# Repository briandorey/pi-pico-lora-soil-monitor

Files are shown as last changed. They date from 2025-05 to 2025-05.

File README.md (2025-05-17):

# Allotment LoRa Wireless Moisture Monitor

This repository contains the hardware and software files for the allotment LoRa wireless moisture monitoring system that can be found on https://www.briandorey.com/post/pi-pico-lora-remote-soil-monitor

The system consists of a sender and receiver, both using a Raspberry Pi Pico and a LoRa wireless module. The sensor reads moisuture, temperature and humitidy values from a series of sensors and sends the data wirelessly to the receiver module using the LoRa wireless protocol.

## Components
###  1. AllotmentSender
   - Hardware: Includes the design and implementation of the sender's physical components.
   - Firmware: Software running on the sender hardware to read sensor data, update an e-paper display and send the data to the home receiver via a LoRa module.

### 2. Home Receiver
   - Hardware: Details about the receiver's physical components.
   - Firmware: Software running on the receiver hardware to handle incoming LoRa data and relay it to an MQTT broker

## License

MIT License

Copyright (c) 2025 Brian Dorey

Permission is hereby granted, free of charge, to any person obtaining a copy of this software and associated documentation files (the "Software"), to deal in the Software without restriction, including without limitation the rights to use, copy, modify, merge, publish, distribute, sublicense, and/or sell copies of the Software, and to permit persons to whom the Software is furnished to do so, subject to the following conditions:

The above copyright notice and this permission notice shall be included in all copies or substantial portions of the Software.

THE SOFTWARE IS PROVIDED "AS IS", WITHOUT WARRANTY OF ANY KIND, EXPRESS OR IMPLIED, INCLUDING BUT NOT LIMITED TO THE WARRANTIES OF MERCHANTABILITY, FITNESS FOR A PARTICULAR PURPOSE AND NONINFRINGEMENT. IN NO EVENT SHALL THE AUTHORS OR COPYRIGHT HOLDERS BE LIABLE FOR ANY CLAIM, DAMAGES OR OTHER LIABILITY, WHETHER IN AN ACTION OF CONTRACT, TORT OR OTHERWISE, ARISING FROM, OUT OF OR IN CONNECTION WITH THE SOFTWARE OR THE USE OR OTHER DEALINGS IN THE SOFTWARE.

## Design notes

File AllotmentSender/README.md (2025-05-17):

# Allotment Sender

This directory contains the hardware and software components and documentation for the Sender module. Full details for the allotment LoRa wireless moisture monitoring system that can be found on https://www.briandorey.com/post/pi-pico-lora-remote-soil-monitor

Below is a summary of the contents:

- **Hardware**: PCB files for the sender hardware.
- **sender-firmware**: Raspberry Pi Pico firmware for the sender in MicroPython.

The allotment sender consists of the following components.

[Raspberry Pi Pico](https://www.raspberrypi.com/documentation/microcontrollers/pico-series.html#pico-1-family) microcontroller  
[Waveshare Pico-LoRa-SX1262-868M](https://www.waveshare.com/wiki/Pico-LoRa-SX1262-868M) LoRa module  
[AB Electronics UK ADC Pi](https://www.abelectronics.co.uk/p/69/adc-pi) analogue to digital converter  
[Microchip MCP9803](https://www.microchip.com/en-us/product/MCP9803) temperature sensor  
AHT20 temperature and humidity sensor  
[WeAct 2.9 Inch E-paper Module](https://www.aliexpress.com/item/1005004644515880.html)

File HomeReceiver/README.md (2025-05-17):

# Home-Receiver

This directory contains the files for the home receiver part of the allotment LoRa wireless moisture monitoring system that can be found on https://www.briandorey.com/post/pi-pico-lora-remote-soil-monitor

The receiver consists of a [Raspberry Pi Pico W](https://www.raspberrypi.com/documentation/microcontrollers/pico-series.html#pico-1-family) connected to a [Waveshare Pico-LoRa-SX1262-868M](https://www.waveshare.com/wiki/Pico-LoRa-SX1262-868M) module.

## Configuration

config.py contains all of the receiver program configuration options.

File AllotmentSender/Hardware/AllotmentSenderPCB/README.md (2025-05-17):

# Allotment Sender

This directory contains the PCB files for the sender hardware. Full details for the allotment LoRa wireless moisture monitoring system that can be found on https://www.briandorey.com/post/pi-pico-lora-remote-soil-monitor

Subdirectories

- **bom**: HTML bom showing the locations of the components on the PCB.
- **production**: Gerber files and production files needed to manufacture the board.

The PCB was designed with Kicad version 9.0.1.

## KiCad

KiCad is an open-source software suite for creating electronic circuit designs and PCB layouts. It provides tools for schematic capture, PCB layout, and 3D visualization of the design.

You can download KiCad from the official website: https://kicad.org/download/

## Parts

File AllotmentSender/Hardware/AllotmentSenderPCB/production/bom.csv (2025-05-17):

Designator | Footprint | Quantity | Value | LCSC Part #
A1 | RaspberryPi_Pico_Common_THT | 1 | RaspberryPi_Pico
C1 | 0805 | 1 | 1µF
C2, C4 | 0805 | 2 | 10µF
C3, C6 | 0805 | 2 | 10nF
C5 | 0805 | 1 | 100nF
J1 | Raspberry_Pi_Zero_Socketed_THT | 1 | Raspberry Pi Header
J2 | PinHeader_1x08_P2.54mm_Vertical | 1 | Screw_Terminal_3V3
J3 | PinHeader_1x08_P2.54mm_Vertical | 1 | Screw_Terminal_GND
J4 | Samtec_HPM-02-01-x-S_Straight_1x02_Pitch5.08mm | 1 | POWER_IN
J5 | PinHeader_1x05_P2.54mm_Vertical | 1 | I2C Bus
J6 | PinHeader_1x03_P2.54mm_Vertical | 1 | UART
R1 | 0805 | 1 | 2K3
R2 | 0805 | 1 | 1K
R3, R4, R5 | 0805 | 3 | 10K
U1 | Pico-LoRa-SX1262-868M | 1 | Pico-LoRa-SX1262-868M
U2 | SOIC-8-1EP_3.9x4.9mm_P1.27mm_EP2.41x3.81mm | 1 | LP3878-ADJ
U3 | PinHeader_1x08_P2.54mm_Vertical | 1 | 2.9" Epaper Module
U4 | SOIC-8_3.9x4.9mm_P1.27mm | 1 | MCP9803

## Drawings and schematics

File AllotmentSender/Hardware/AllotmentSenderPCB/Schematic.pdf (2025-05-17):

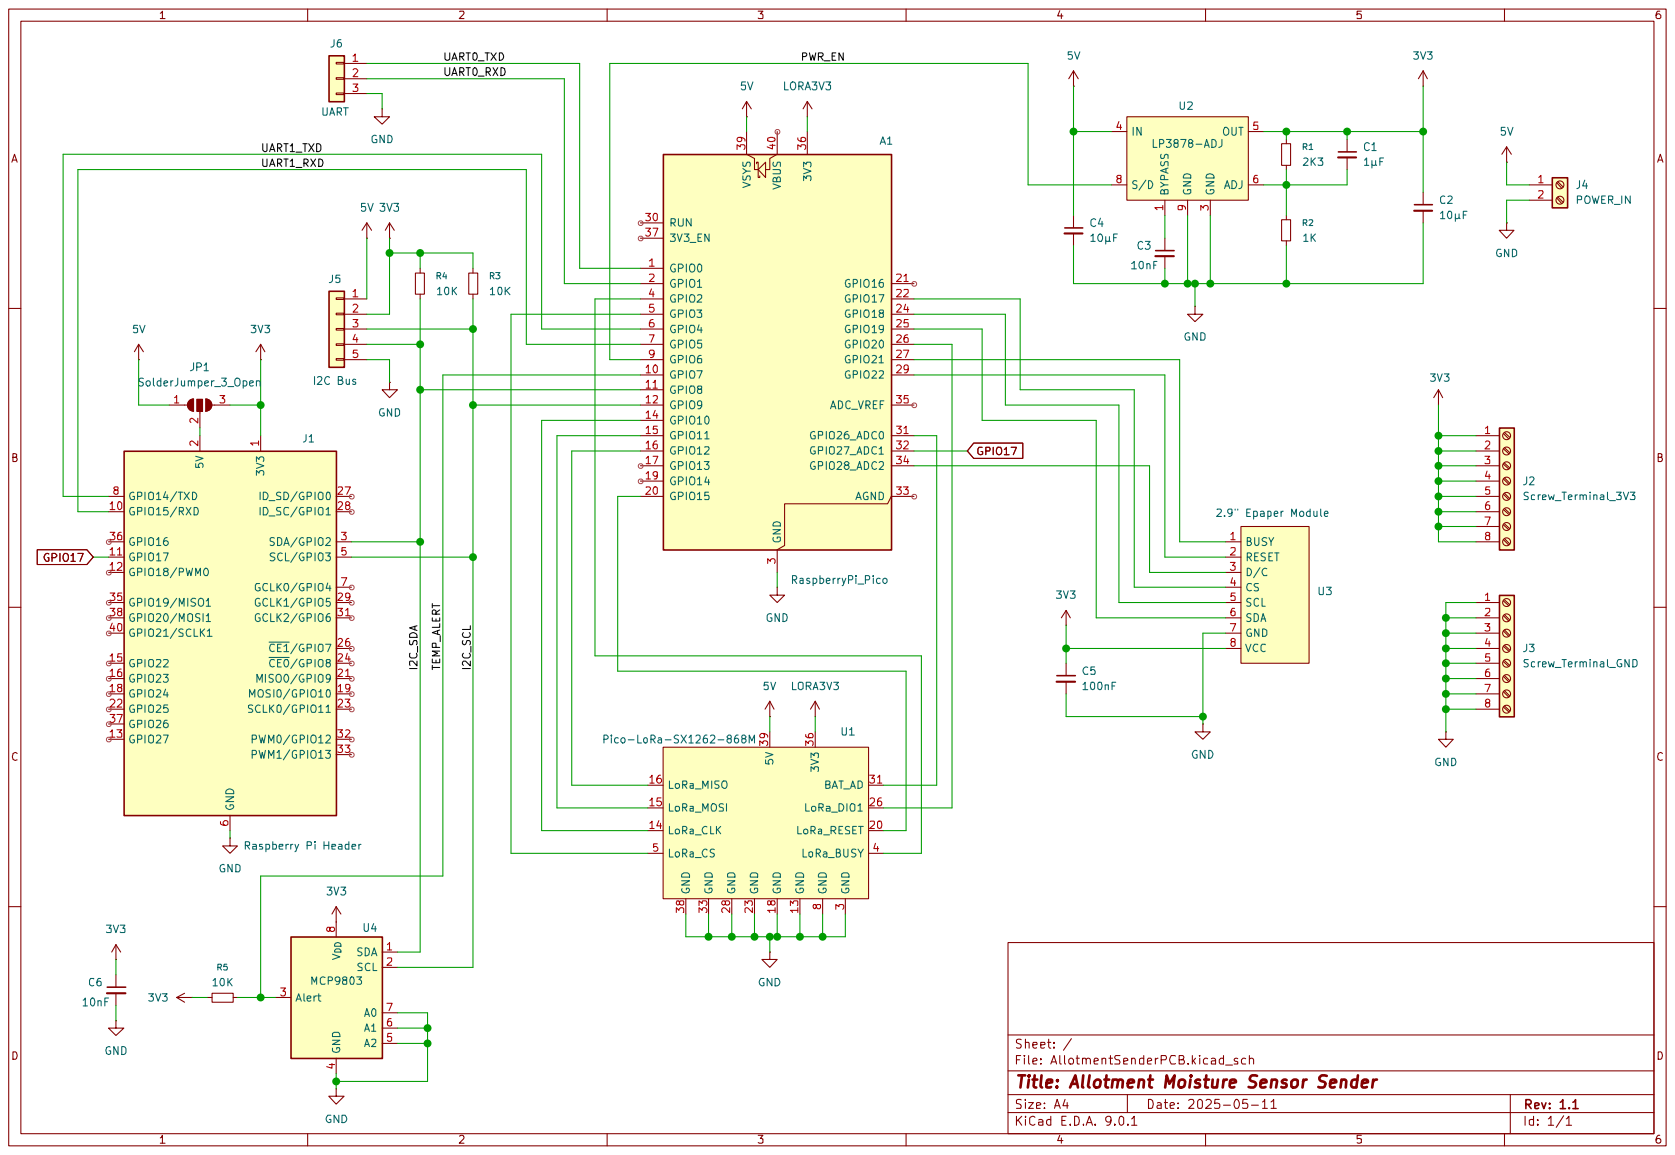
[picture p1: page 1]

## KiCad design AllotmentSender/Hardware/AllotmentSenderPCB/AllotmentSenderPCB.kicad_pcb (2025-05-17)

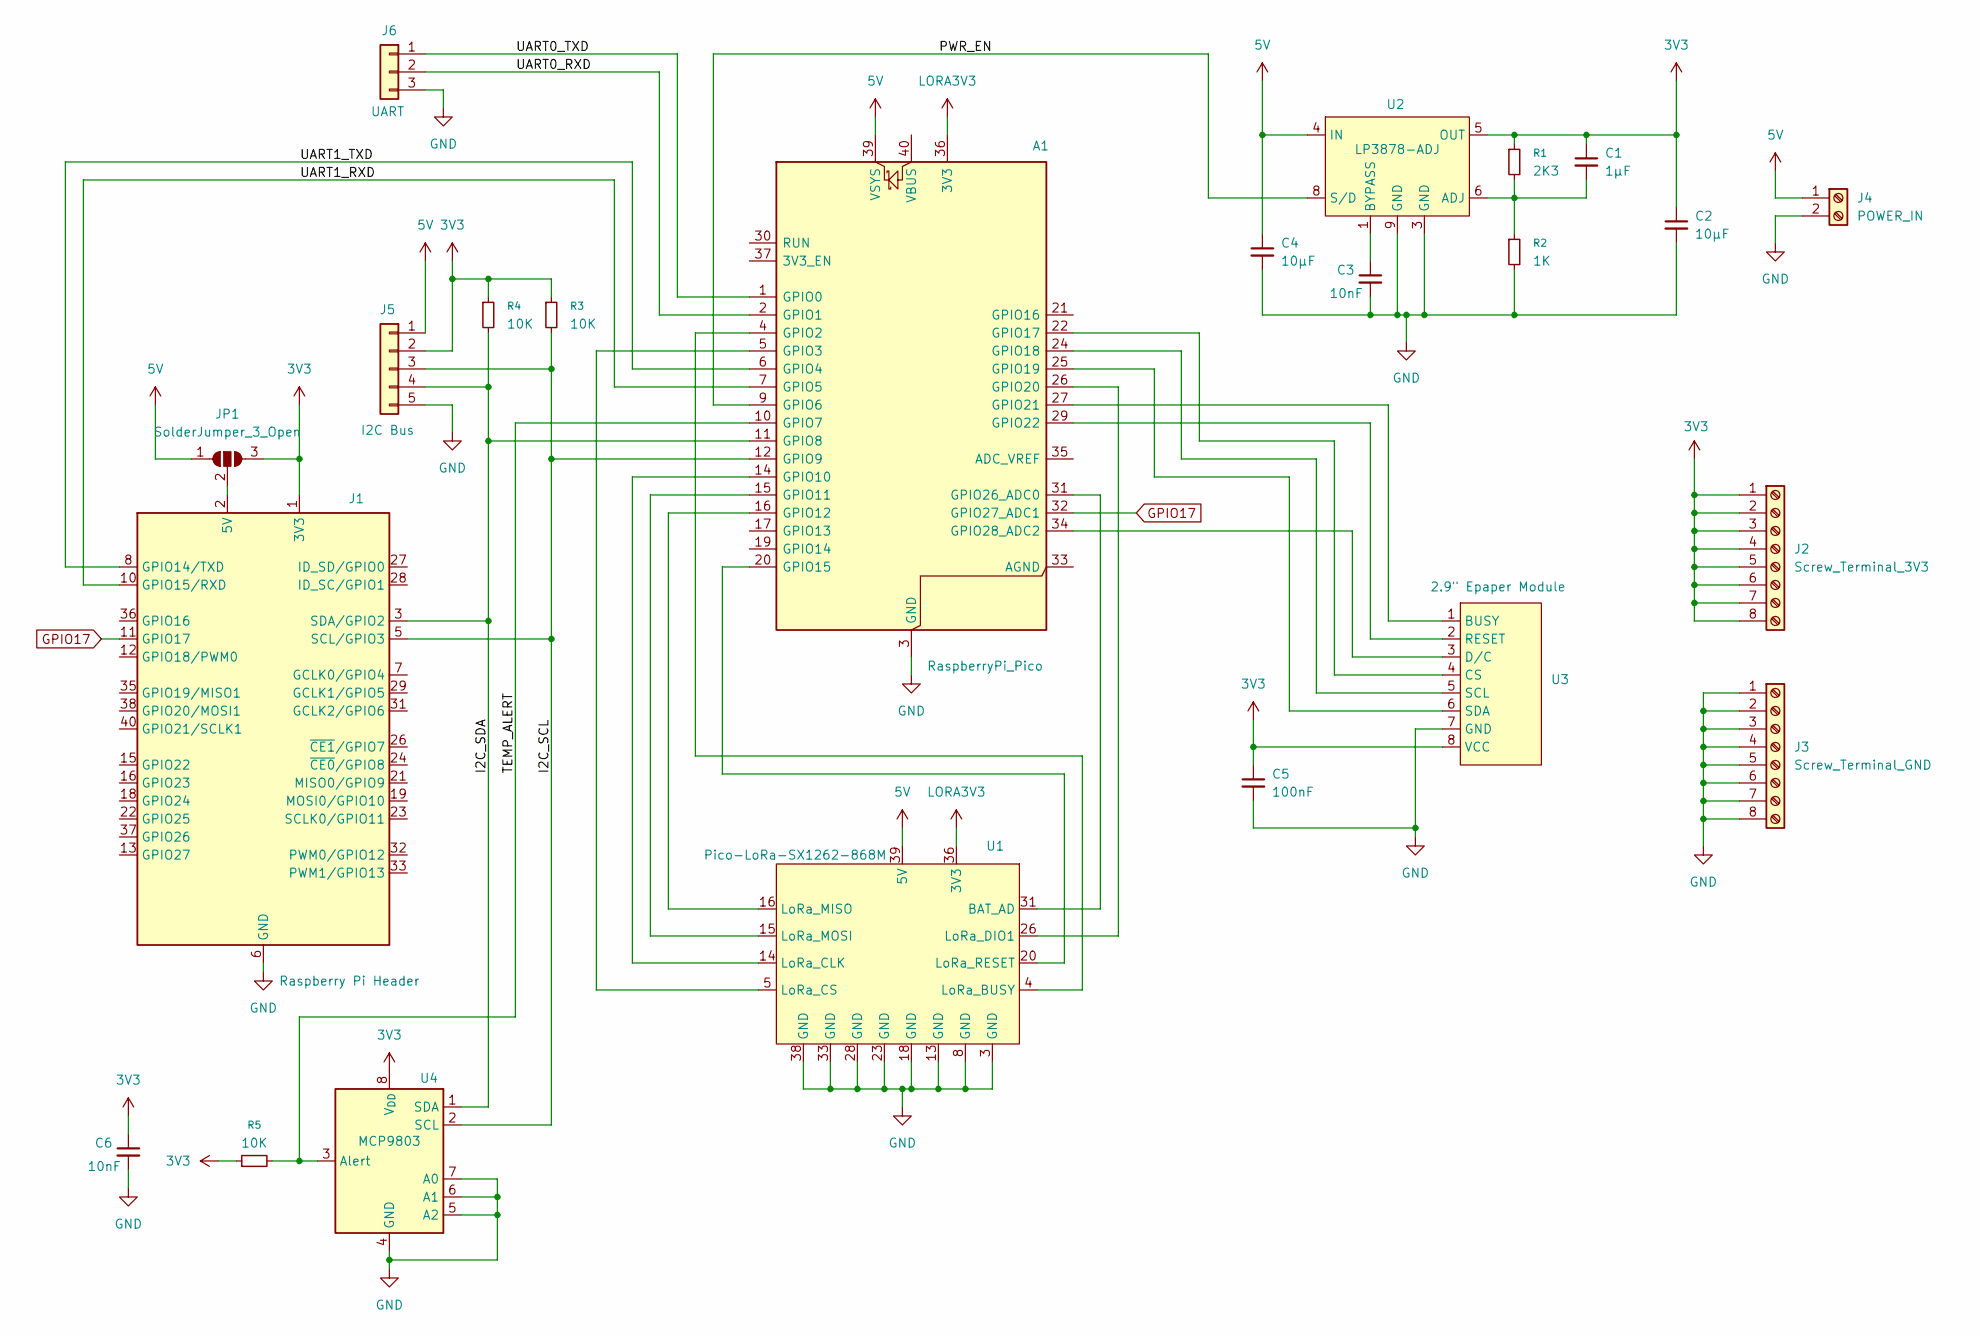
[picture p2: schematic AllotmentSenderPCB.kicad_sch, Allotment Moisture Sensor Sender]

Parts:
A1: RaspberryPi_Pico; RaspberryPi_Pico_Common_THT
C1: 1µF; C_0805_2012Metric
C2, C4: 10µF; C_0805_2012Metric
C3, C6: 10nF; C_0805_2012Metric
C5: 100nF; C_0805_2012Metric
J1: Raspberry Pi Header; Raspberry_Pi_Zero_Socketed_THT
J2: Screw_Terminal_3V3; PinHeader_1x08_P2.54mm_Vertical
J3: Screw_Terminal_GND; PinHeader_1x08_P2.54mm_Vertical
J4: POWER_IN; Samtec_HPM-02-01-x-S_Straight_1x02_Pitch5.08mm
J5: I2C Bus; PinHeader_1x05_P2.54mm_Vertical
J6: UART; PinHeader_1x03_P2.54mm_Vertical
JP1: SolderJumper_3_Open; PinHeader_1x03_P2.54mm_Vertical
R1: 2K3; R_0805_2012Metric
R2: 1K; R_0805_2012Metric
R3, R4, R5: 10K; R_0805_2012Metric
U1: Pico-LoRa-SX1262-868M
U2: LP3878-ADJ; SOIC-8-1EP_3.9x4.9mm_P1.27mm_EP2.41x3.81mm
U3: 2.9" Epaper Module; PinHeader_1x08_P2.54mm_Vertical
U4: MCP9803; SOIC-8_3.9x4.9mm_P1.27mm

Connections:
3V3: C1.1, C2.1, C5.1, C6.1, J1.1 (3V3), J1.17 (3V3), J2.1, J2.2, J2.3, J2.4, J2.5, J2.6, J2.7, J2.8, J5.2, JP1.3 (B), R1.1, R3.1, R4.1, R5.1, U2.5 (OUT), U3.8 (VCC), U4.8 (V_{DD})
5V: A1.39 (VSYS), C4.1, J4.1, J5.1, JP1.1 (A), U1.39 (5V), U2.4 (IN)
/I2C_SCL: A1.12 (GPIO9), J1.5 (SCL/GPIO3), J5.3, R3.2, U4.2 (SCL)
/I2C_SDA: A1.11 (GPIO8), J1.3 (SDA/GPIO2), J5.4, R4.2, U4.1 (SDA)
/PWR_EN: A1.9 (GPIO6), U2.8 (S/D)
/TEMP_ALERT: A1.10 (GPIO7), R5.2, U4.3 (Alert)
/UART0_RXD: A1.2 (GPIO1), J6.2
/UART0_TXD: A1.1 (GPIO0), J6.1
/UART1_RXD: A1.7 (GPIO5), J1.10 (GPIO15/RXD)
/UART1_TXD: A1.6 (GPIO4), J1.8 (GPIO14/TXD)
GND: A1.3 (GND), A1.8 (GND), A1.13 (GND), A1.18 (GND), A1.23 (GND), A1.28 (GND), A1.38 (GND), C2.2, C3.2, C4.2, C5.2, C6.2, J1.6 (GND), J1.9 (GND), J1.14 (GND), J1.20 (GND), J1.25 (GND), J1.30 (GND), J1.34 (GND), J1.39 (GND), J3.1, J3.2, J3.3, J3.4, J3.5, J3.6, J3.7, J3.8, J4.2, J5.5, J6.3, R2.2, U1.3 (GND), U1.8 (GND), U1.13 (GND), U1.18 (GND), U1.23 (GND), U1.28 (GND), U1.33 (GND), U1.38 (GND), U2.3 (GND), U2.9 (GND), U3.7 (GND), U4.4 (GND), U4.5 (A2), U4.6 (A1), U4.7 (A0)
GPIO17: A1.32 (GPIO27_ADC1), J1.11 (GPIO17)
LORA3V3: A1.36 (3V3), U1.36 (3V3)
unnamed: A1.4 (GPIO2), U1.4 (LoRa_BUSY)
unnamed: A1.5 (GPIO3), U1.5 (LoRa_CS)
unnamed: A1.14 (GPIO10), U1.14 (LoRa_CLK)
unnamed: A1.15 (GPIO11), U1.15 (LoRa_MOSI)
unnamed: A1.16 (GPIO12), U1.16 (LoRa_MISO)
unnamed: A1.20 (GPIO15), U1.20 (LoRa_RESET)
unnamed: A1.22 (GPIO17), U3.4 (CS)
unnamed: A1.24 (GPIO18), U3.5 (SCL)
unnamed: A1.25 (GPIO19), U3.6 (SDA)
unnamed: A1.26 (GPIO20), U1.26 (LoRa_DIO1)
unnamed: A1.27 (GPIO21), U3.1 (BUSY)
unnamed: A1.29 (GPIO22), U3.2 (RESET)
unnamed: A1.31 (GPIO26_ADC0), U1.31 (BAT_AD)
unnamed: A1.34 (GPIO28_ADC2), U3.3 (D/C)
unnamed: J1.2 (5V), J1.4 (5V), JP1.2 (C)
unnamed: C1.2, R1.2, R2.1, U2.6 (ADJ)
unnamed: C3.1, U2.1 (BYPASS)

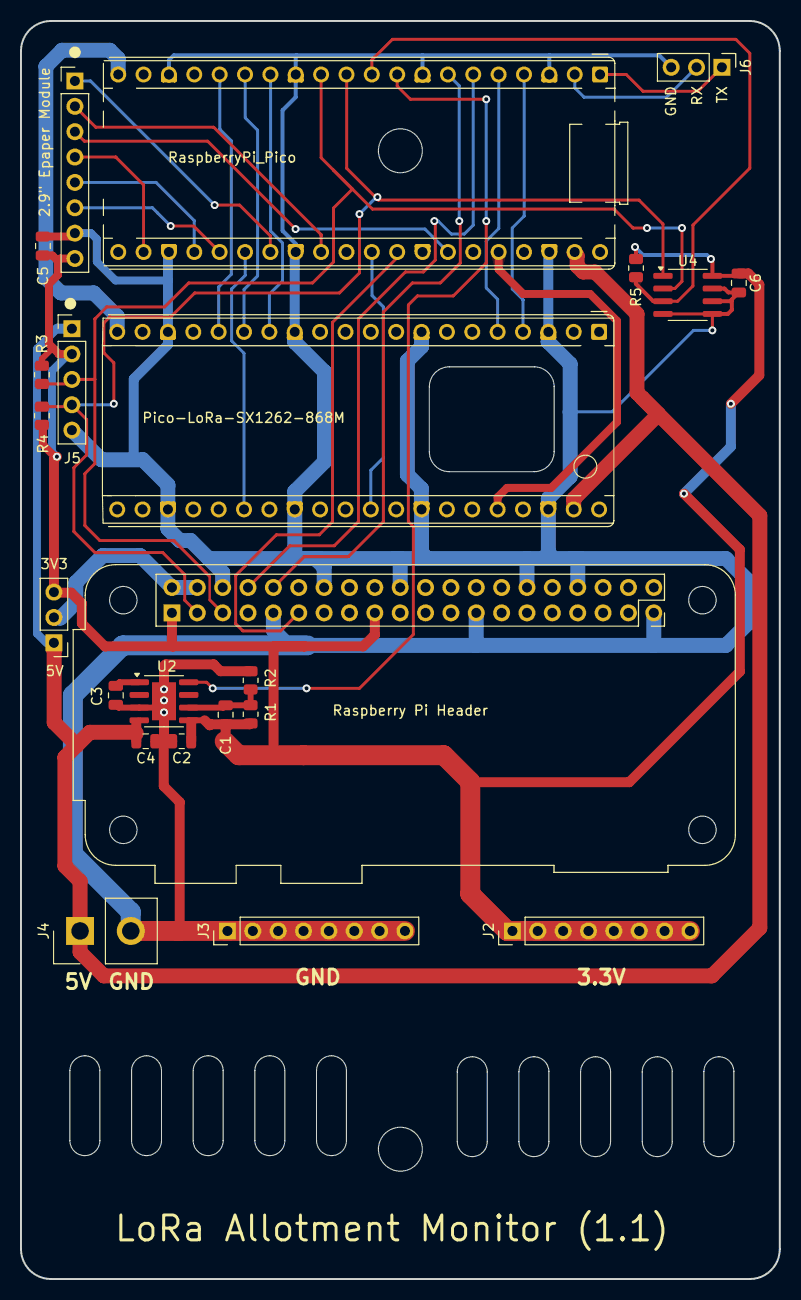
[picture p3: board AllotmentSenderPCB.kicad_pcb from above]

Board: 2 copper layers, 76.0 x 126.0 mm, 23 parts (0 on the bottom side), 30 nets.

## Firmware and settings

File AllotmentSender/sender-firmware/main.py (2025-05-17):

# LoRa Sensor Node
# This script reads data from various sensors, sends the data via LoRa, and updates a display.
# It uses the SX1262 LoRa module, an ADC Pi for moisture sensors, a MCP9803 for board temperature
# and an AHT20 for temperature and humidity.
# The script is designed to run on a Raspberry Pi Pico and uses the EPD_2in9_B_V4_Portrait display.

# MIT License
# 
# Copyright (c) 2025 Andrew Dorey
# 
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

from lib.sx1262 import SX1262
import time
import ujson
from machine import Pin, reset, I2C, WDT
from lib.ADCPi import ADCPi
from lib.mcp9803 import MCP9803
from lib.aht20 import AHT20
from lib.display import EPD_2in9_B_V4_Portrait
from config import * # Import all variables from config


# Pico Pin Connections
led = Pin(25, Pin.OUT) # LED on Raspberry Pi Pico
psu = Pin(6, Pin.OUT) # 3.3V Regulator enable pin
temperature_alert = Pin(7, Pin.IN) # MCP9803 Temperature Alert Pin
rpi_gpio17 = Pin(27, Pin.OUT) # Raspberry Pi Header GPIO17 pin

# Watchdog Timer
wdt = WDT(timeout=8000)  # 8 second timeout

# Flags
lora_initialized = False
adc_initialized = False
mcp9803_initialized = False
aht20_initialized = False
send_complete = False
send_timeout = False

#Global variables
moisture_values: list[float] = [0.0] * 8
temperature, humidity = 0.0, 0.0
board_temperature = 0.0
date: str = "01/01/2000 00:00:00"   
snr: float = 0.0

# Initialise communication buses
i2c = I2C(I2C_BUS, sda=I2C_SDA, scl=I2C_SCL, freq=I2C_FREQ)
lora_module = SX1262(spi_bus=LORA_SPIBUS, clk=LORA_CLK, mosi=LORA_MOSI, miso=LORA_MISO, cs=LORA_CS, irq=LORA_IRQ, rst=LORA_RST, gpio=LORA_GPIO)


def initialize_lora() -> int:
    """
    Initialize the LoRa module.
    """


    global lora_initialized, power
    try:
        # Load the LoRa power level from flash memory
        power: int = read_lora_power_from_flash()

        if power is not None:
            print("Loaded LoRa power level from flash:", power)
        else:
            power = LORA_POWER
            print("No LoRa power level found in flash, using default:", power)

        if int(power) >= LORA_MAX_POWER:
            power = LORA_POWER
            print("LoRa power level in flash is 10, using default:", power)

        # SX1262 LoRa module configuration
        lora_module.begin(freq=LORA_FREQUENCY, bw=LORA_BANDWIDTH, sf=LORA_SPREADINGFACTOR, cr=LORA_CODINGRATE, 
                syncWord=LORA_SYNCWORD, power=power, currentLimit=LORA_CURRENTLIMIT, 
                preambleLength=LORA_PREAMBLELENGTH, implicit=False, implicitLen=0xFF, 
                crcOn=True, txIq=False, rxIq=False, tcxoVoltage=1.7, useRegulatorLDO=False, blocking=True)
        lora_initialized = True
        print("LoRa module initialized successfully.")
        return power
    except Exception as e:
        print("Error initializing LoRa module:", e)
        lora_initialized = False
        return 0

def save_lora_power_to_flash(value):
    """Save a value to flash memory"""
    with open('lora.txt', 'w') as f:
        f.write(str(value))

def read_lora_power_from_flash() -> int:
    """Read a value from flash memory"""
    try:
        with open('lora.txt', 'r') as f:
            return int(f.read())
    except OSError:  # File doesn't exist
        return 0

def wakeup_devices() -> None:
    """
    Wake up the devices
    """
    psu.on() # Turn on the 3.3V regulator
    time.sleep(0.1) # Wait for the regulator to stabilize
    return

def sleep_devices() -> None:
    """
    Put the devices to sleep
    """
    psu.off() # Turn off the 3.3V regulator
    return

def adc_to_moisture_percent(adc_value) -> int:
    """
    Convert ADC value to moisture percentage
    :param adc_value: ADC value
    :return: Moisture percentage
    """
    if adc_value >= V_OPEN:
        return -1
    elif adc_value <= V_DISCONNECT:
        return -2
    else:
        # Calculate the moisture percentage using the formula
        moisture = 100 * (V_DRY - adc_value) / (V_DRY - V_WET)
        if moisture < 0:
            return 0
        elif moisture > 100:
            return 100
        else:
            return int(moisture)


def get_moisture() -> list[float]:
    """
    Get moisture readings from the ADC Pi
    """
    try:
        # Initialise ADC inputs using an ADC Pi from AB Electronics UK
        adc = ADCPi(0x68, 0x69, 12,sda=I2C_SDA,scl=I2C_SCL) 

        moisture: list[float] = [0.0] * 8
        # Read the moisture values from the ADC Pi
        for i in range(8):
            moisture[i] = adc_to_moisture_percent(adc.read_voltage(i + 1))
    except Exception as e:
        print("Error reading moisture values:", e)
        moisture = [0.0] * 8

    return moisture

def get_board_temperature() -> float:
    """
    Get the board temperature from the MCP9803
    """
    # Initialise MCP9803 temperature sensor
    
    try:
        mcp9803 = MCP9803(address=0x48, sda=I2C_SDA, scl=I2C_SCL, freq=I2C_FREQ, i2cbus=I2C_BUS)
        board_temperature: float = mcp9803.read_temperature()
    except Exception as e:
        print("Error reading board temperature:", e)
        board_temperature = 0.0
    return board_temperature

def get_temperature_and_humidity() -> tuple[float, float]:
    """
    Get the polytunnel temperature and humidity from the AHT20
    """
    try:
        # Initialise AHT20 temperature and humidity sensor
        i2c = I2C(I2C_BUS, sda=I2C_SDA, scl=I2C_SCL, freq=I2C_FREQ)
        aht20 = AHT20(i2c)
        aht20.initialize_sensor()
        aht20.soft_reset()

        # Get the temperature and humidity values
        temperature, humidity = aht20.get_temperature_and_humidity()
    except Exception as e:
        print("Error reading temperature and humidity:", e)
        temperature = 0.0
        humidity = 0.0
    return temperature, humidity

def get_data() -> bool:
    """
    Create a JSON object with the moisture and temperature data.
    :param date: Date string
    :return: JSON object as bytes
    """
    # Wake up the devices
    wakeup_devices()

    global date, moisture_values, board_temperature, temperature, humidity

    # Get the moisture and temperature data
    moisture_values: list[float] =  get_moisture()
    temperature, humidity = get_temperature_and_humidity()
    board_temperature = get_board_temperature()
    
    # Sleep the devices
    sleep_devices()   

    return True

def get_json_string(data) -> bytes:
    """
    Convert the data to JSON and encode it as bytes.
    :param data: Data to convert
    :return: JSON object as bytes
    """

    global date, moisture_values, board_temperature, temperature, humidity

    # Create a JSON object with the data
    data = {
        "date": date,
        "moisture1": moisture_values[0],
        "moisture2": moisture_values[1],
        "moisture3": moisture_values[2],
        "moisture4": moisture_values[3],
        "moisture5": moisture_values[4],
        "moisture6": moisture_values[5],
        "moisture7": moisture_values[6],
        "moisture8": moisture_values[7],
        "board_temperature": board_temperature,
        "temperature": temperature,
        "humidity": humidity
    }

    json_string: str = ujson.dumps(data)
    return json_string.encode('utf-8')

def send_data(sx, lora_power) -> bool:
    """
    Send the data to the LoRa module.
    """
    global send_complete, send_timeout, date
    send_timeout = False
    wdt.feed()

    print(f"Trying with power {power} dBm...")
    sx.setOutputPower(lora_power)
    sx.send(b"ping")
    print("Waiting for response...")
    # Now wait for response
    response, err = sx.recv(timeout_en=True, timeout_ms=2000)

    print(response)
    if response:
        print("Received:", response)
        print("Errors:", err)
        try:
            if response[:5] == b'pong;':
                # Parse SNR from message
                date = response[5:24]
                snr = float(response[26:])
                print("date: " + str(date))
                print("snr: " + str(snr))

                if snr >= MIN_SNR:
                    print("SNR acceptable. Done.")
                    save_lora_power_to_flash(lora_power)
                else:
                    print("SNR too low. Adjusting power.")
                    return False
            else:
                print("Unexpected response.")
                return False
        except Exception as e:
            print("Error decoding response:", e)

    else:
        print("No response received.")
        return False

    # Send the data to the LoRa module
    lora_module.send(get_json_string(date))
    # Now wait for response
    response, err = sx.recv(timeout_en=True, timeout_ms=2000)

    if response:
        print("Received:", response)
        print("Errors:", err)
        if response[:5] == b'ok':
            print("Data sent successfully.")
            send_complete = True
            return True
        else:
            print("Error sending data.")
            send_timeout = True
            return False

    return False
   

def update_display() -> None:
    """
    Update the display with the given data.
    :param data: Data to display
    """
    global date, moisture_values, board_temperature, temperature, humidity, send_timeout, wdt

    try:
        # Wake up the devices
        wakeup_devices()

        display = EPD_2in9_B_V4_Portrait(DISPLAY_SPIBUS, DISPLAY_SDA, DISPLAY_SCK, DISPLAY_CS, DISPLAY_DC, DISPLAY_RST, DISPLAY_BUSY, wdt)

        if send_timeout:
            date_string = "LoRa TX Failed..."
        else:
            date_string: str = date

        # Draw the display
        draw_display(display, date_string, moisture_values, board_temperature, temperature, humidity)   

    except Exception as e:
        print("Error updating display:", e)

    sleep_devices()

    return

def draw_display(epd, date_string, moisture_values, board_temperature, temperature, humidity):
    
    epd.Clear()
    epd.imageblack.fill(0xFF)

    epd.imageblack.text(date_string, 0, 3, 0x00)
    epd.imageblack.text("TEMP:     " + "{:.1f}".format(temperature) + "C", 3, 146, 0x00)
    epd.imageblack.text("HUMIDITY: " + "{:.1f}".format(humidity) + "%", 3, 158, 0x00)
    epd.imageblack.fill_rect(0, 16, 50, 2, 0x00) # black outline
    epd.imageblack.fill_rect(78, 16, 50, 2, 0x00) # black outline
        
    # Moisture Boxes

    draw_moisture_box(epd, 3, 21, moisture_values[0])
    draw_moisture_box(epd, 3, 81, moisture_values[1])
    draw_moisture_box(epd, 85, 21, moisture_values[2])
    draw_moisture_box(epd, 85, 81, moisture_values[3])
    draw_moisture_box(epd, 3, 169, moisture_values[4])
    draw_moisture_box(epd, 85, 169, moisture_values[5])
    draw_moisture_box(epd, 3, 233, moisture_values[6])
    draw_moisture_box(epd, 85, 233, moisture_values[7])

    epd.display()
    epd.delay_ms(2000)
    epd.sleep()

def draw_moisture_box(epd, x: int, y: int, moisture: int) -> None:
    epd.imageblack.fill_rect(x, y, 40, 58, 0x00) # black outline
    epd.imageblack.fill_rect(x + 2, y + 2, 36, 54, 0xFF) # white box

    if moisture < 0: # If the moisture is invalid
        if moisture == -1: # If the moisture is open circuit
            epd.imageblack.text("Open", x + 5, y + 40, 0x00) # black text            
        elif moisture == -2: # If the moisture is disconnected
            epd.imageblack.text("NC", x + 12, y + 40, 0x00) # black text
    
    fill_height = int(moisture / 2)
    if moisture >= MOISTURE_SENSOR_IDEAL_DRY: # If the moisture is above the dry value
        epd.imageblack.fill_rect(x + 3, y + 4 + (50 - fill_height), 34, fill_height, 0x00) # black fill
        if moisture >= MOISTURE_SENSOR_IDEAL_WET: # If the moisture is above the wet value
            epd.imageblack.text("WET", x + 8, y + 38, 0xFF) # black text

    else: # If the moisture is below the dry value
        epd.imagered.fill_rect(x + 3, y + 4 + (50 - fill_height), 34, fill_height, 0xFF) # red fill
        epd.imagered.ellipse(x + 20, y + 8, 3, 3, 0xFF, True) # red circle
        epd.imagered.ellipse(x + 20, y + 20, 3, 3, 0xFF, True) # red circle
        epd.imagered.ellipse(x + 20, y + 30, 3, 3, 0xFF, True) # red circle
        epd.imagered.fill_rect(x + 17, y + 10, 7, 10, 0xFF) # red fill
    return

def blink_led(count = 1) -> None:
    """
    Blink the LED a given number of times.
    :param count: Number of times to blink
    """
    for _ in range(count):
        led.on()
        time.sleep(0.1)
        led.off()
        time.sleep(0.1)
    return

def main() -> None:
    """
    Main function to initialize the LoRa module and start the main loop.
    """
    # Initialize watchdog at the start
    #wdt = WDT(timeout=10000)  # 10 second timeout

    global lora_initialized, power, send_complete, send_timeout

    wdt.feed()

    blink_led(1) # Blink the LED once to indicate startup

    try:
        while True:
            data_success: bool = get_data() # Get the data from the sensors

            if not data_success:
                print("Failed to get data from sensors.")
                time.sleep(SLEEP_TIME) # Go to sleep
                reset() # Reset the device
            
            power = initialize_lora()

            wdt.feed()

            if lora_initialized:
                blink_led(2) # Blink the LED two times to indicate LoRa initialization

                if power is None:
                    power = LORA_POWER

                # Send the data to the LoRa module
                while not send_complete and not send_timeout:
                    send_data(lora_module, power)
                    power = power + 1
                    if power > LORA_MAX_POWER:
                        print("Max power reached, stopping.")
                        break                    
                if not send_complete:                    
                    print("Failed to send data to LoRa module.")
                    send_timeout = True
                    blink_led(6) # Blink the LED six times to indicate failure
                else:
                    blink_led(3) # Blink the LED three times to indicate success


            wdt.feed()
            
            print("Updating display with data...")
            update_display()

            print("Sleeping...")
            time.sleep(SLEEP_TIME)
            reset() # Reset the device

    except Exception as e:
        print("Fatal error:", e)
        # Reset on error
        reset()


if __name__ == "__main__":
    main()

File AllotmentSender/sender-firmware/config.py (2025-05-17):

# Constants
SLEEP_TIME: int = 600 # Sleep time in seconds (10 minutes)


# Reference voltages based on your calibration
V_DRY = 0.80   # Sensor voltage in dry soil (0%)
V_WET = 0.46   # Sensor voltage in wet soil (100%)
V_OPEN = 1.00  # Sensor miniumum voltage in open air
V_DISCONNECT = 0.2  # Sensor maximum voltage when disconnected
MAX_MOISTURE = 34  # Maximum calibrated moisture percentage

# Moisture Sensor Min/Max Values
MOISTURE_SENSOR_DRY = 15 # Dry moisture sensor value
MOISTURE_SENSOR_IDEAL_DRY = 20 # Ideal dry moisture sensor value
MOISTURE_SENSOR_IDEAL_WET = 35 # Ideal wet moisture sensor value
MOISTURE_SENSOR_WET = 40 # Saturated moisture sensor value

# RPI Header Pin Definitions
RPIHEADER_GPIO17 = 27 # GPIO 17 on the Raspberry Pi header - connects to GPIO27 on Raspberry Pi Pico
RPIHEADER_UART_TX = 4 # UART TX on the Raspberry Pi header - connects to GPIO4 on Raspberry Pi Pico
RPIHEADER_UART_RX = 5 # UART RX on the Raspberry Pi header - connects to GPIO5 on Raspberry Pi Pico

# E-paper Display Pin Definitions
DISPLAY_SPIBUS = 0 # SPI bus number
DISPLAY_SDA = 19 # GPIO19 on Raspberry Pi Pico
DISPLAY_SCK = 18 # GPIO18 on Raspberry Pi Pico
DISPLAY_CS = 17 # GPIO17 on Raspberry Pi Pico
DISPLAY_DC = 28 # GPIO28 on Raspberry Pi Pico
DISPLAY_RST = 22 # GPIO22 on Raspberry Pi Pico
DISPLAY_BUSY = 21 # GPIO21 on Raspberry Pi Pico

# LORA Module Pin Definitions
LORA_SPIBUS = 1 # SPI bus number
LORA_MOSI = 11 # GPIO11 on Raspberry Pi Pico
LORA_MISO = 12 # GPIO12 on Raspberry Pi Pico
LORA_CLK = 10 # GPIO10 on Raspberry Pi Pico
LORA_CS = 3 # GPIO3 on Raspberry Pi Pico
LORA_RST = 15 # GPIO15 on Raspberry Pi Pico
LORA_GPIO = 2 # GPIO2 on Raspberry Pi Pico 
LORA_IRQ = 20 # GPIO20 on Raspberry Pi Pico

# I2C Bus Pin Definitions
# The I2C bus is used for communication with the AHT20 and MCP9803 sensors.
I2C_BUS = 0 # I2C bus number
I2C_SDA = 8 # GPIO8 on Raspberry Pi Pico
I2C_SCL = 9 # GPIO9 on Raspberry Pi Pico
I2C_FREQ = 100000 # I2C frequency

# LoRa Configuration Constants
# These constants are used to configure the LoRa module and should be set according to your requirements.
LORA_FREQUENCY=868 # Frequency in MHz
LORA_BANDWIDTH=500.0 # Bandwidth in kHz
LORA_SPREADINGFACTOR=12 # Spreading factor (7-12)
LORA_CODINGRATE=8 # Coding rate (5-8)
LORA_SYNCWORD=0x18 # Sync word for private networks
LORA_POWER=-9 # Transmit power in dBm
LORA_MAX_POWER=22 # Maximum transmit power in dBm
LORA_CURRENTLIMIT=60.0 # Current limit in mA
LORA_PREAMBLELENGTH=8 # Preamble length in symbols

# Define minimum acceptable SNR for communication
# The SNR (Signal-to-Noise Ratio) is a measure of signal quality.
# The LoRa power output will be increased until the SNR is above this threshold.
# This value should be adjusted based on your specific requirements
# and the environment in which the LoRa module operates.
# A higher value means a stronger signal is required for successful communication.
MIN_SNR = -20

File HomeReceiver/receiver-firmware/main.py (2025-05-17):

# This is a simple LoRa receiver that connects to a Wi-Fi network and publishes messages to an MQTT broker.
# It uses the SX1262 LoRa module for communication and handles errors gracefully.
# It also includes a message queue to store messages before sending them to the MQTT broker.
# The code is designed to run on a Raspberry Pi Pico 2 W and uses the MicroPython framework.
#
# MIT License
# 
# Copyright (c) 2025 Andrew Dorey
# 
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
from lib.sx1262 import SX1262
from lib.umqtt.simple import MQTTClient
from machine import Pin, WDT
import network
import socket
import struct
import time
import machine
from config import * # Import all variables from config


# Global Variables
last_day = 0
wifi_retries = 0
wlan = network.WLAN(network.STA_IF)
message_received = False 
led = machine.Pin("LED", machine.Pin.OUT)
wdt = WDT(timeout=8000)  # Watchdog timer set to 5 seconds
lora_module = SX1262(spi_bus=LORA_SPIBUS, clk=LORA_CLK, mosi=LORA_MOSI, miso=LORA_MISO, cs=LORA_CS, irq=LORA_IRQ, rst=LORA_RST, gpio=LORA_GPIO)

class MessageQueue:
    """
    A simple message queue to store messages before sending them to the MQTT broker.
    """

    def __init__(self, max_size=100):
        self.queue = []
        self.max_size = max_size
    
    def add(self, message, topic):
        if len(self.queue) < self.max_size:
            self.queue.append((message, topic))
            return True
        return False
    
    def process_queue(self):
        wdt.feed()  # Feed the watchdog timer
        while self.queue:
            message, topic = self.queue[0]
            try:
                publish_mqtt(message, topic)
                self.queue.pop(0)
            except:
                break  # Stop processing if publication fails


def connect_wifi(max_retries=3, timeout=20):
    """
    Connect to the WiFi network with retry logic
    """
    global wlan, wifi_retries
    attempts = 0
    
    # Add initial delay to allow WiFi hardware to stabilize
    time.sleep(1)

    while attempts < max_retries:
        wdt.feed()  # Feed the watchdog timer
        print(f"Connecting to Wi-Fi: {WIFI_SSID} (Attempt {attempts + 1}/{max_retries})")

        try:
            wlan.active(False)
            time.sleep(1)
            wlan.active(True)
            wlan.config(pm=0xa11140)  # Disable power-saving mode
            wlan.connect(WIFI_SSID, WIFI_PASSWORD)
            
            start_time = time.time()
            while not wlan.isconnected():
                wdt.feed()  # Feed the watchdog timer
                if time.time() - start_time > timeout:
                    raise Exception("WiFi connection timeout")
                print(".", end="")
                time.sleep(1)

                
            print("\nConnected to Wi-Fi:", wlan.ifconfig())
            return True
            
        except Exception as e:
            attempts += 1
            print(f"\nWiFi connection attempt {attempts} failed: {str(e)}")
            if attempts >= max_retries:
                print("Max retries reached. Could not connect to WiFi")
                return False


def publish_mqtt(message, topic):
    """
    Publish a message to the MQTT broker with error handling
    """
    wdt.feed()  # Feed the watchdog timer

    try:
        client = MQTTClient(
            CLIENT_ID, MQTT_BROKER, port=MQTT_PORT, 
            user=MQTT_USERNAME, password=MQTT_PASSWORD
        )
        
        client.connect()
        print("Connected to MQTT Broker")

        client.publish(topic, message)
        print(f"Published message: {message}")
        
    except Exception as e:
        print(f"MQTT Error: {str(e)}")
    finally:
        try:
            client.disconnect()
        except:
            pass

def get_ntp_time():
    """
    Get time from NTP server with retry logic
    """
    NTP_DELTA = 2208988800  # Difference between NTP and Unix epoch (1970)
    host = NTP_SERVER
    max_retries = 10

    for attempt in range(max_retries):
        wdt.feed()  # Feed the watchdog timer

        try:
            # Send request
            s = socket.socket(socket.AF_INET, socket.SOCK_DGRAM)
            addr = socket.getaddrinfo(host, 123)[0][-1]
            msg = b'\x1b' + 47 * b'\0'
            s.sendto(msg, addr)

            # Receive response
            s.settimeout(1)
            msg = s.recv(48)
            s.close()

            # Unpack time
            val = struct.unpack("!I", msg[40:44])[0]
            return val - NTP_DELTA
        except Exception as e:
            print(f"NTP request attempt {attempt + 1} failed: {str(e)}")
            time.sleep(1)  # Wait before retrying

    print("NTP request failed after 10 attempts. Setting clock to 1st January 2000.")
    return time.mktime((2000, 1, 1, 0, 0, 0, 0, 0))



# Set internal RTC
def set_rtc():
    """
    Set the time on the internal RTC from the NTP server
    """
    wdt.feed()  # Feed the watchdog timer

    try:
        # Get the current date and time from the NTP server
        ntp_time = get_ntp_time()
        if ntp_time:
            tm = time.localtime(ntp_time)
            rtc = machine.RTC()
            rtc.datetime((tm[0], tm[1], tm[2], tm[6]+1, tm[3], tm[4], tm[5], 0))
            
            print("RTC set to:", datetime_str(get_rtc()))
        else:
            raise ValueError("NTP time could not be retrieved")
    except Exception as e:
        error_message = f"RTC Error: Could not set RTC. {str(e)}"
        publish_mqtt(error_message, MQTT_MESSAGE_TOPIC)
        print(error_message)

def get_rtc():
    """
    Get the time from the internal RTC
    """
    rtc = machine.RTC()
    return rtc.datetime()

def get_day() -> type[int]:
    rtc = machine.RTC()
    return rtc.datetime()[3]

def datetime_str(timestamp):  
    """
    Format the date as an ISO Date string
    """  
    datestring="%04d-%02d-%02dT%02d:%02d:%02dZ"%(timestamp[0:3] + timestamp[4:7])
    return datestring
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

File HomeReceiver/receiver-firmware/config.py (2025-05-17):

import ubinascii
import network
# Configuration file for the LoRa and Wi-Fi settings

# LORA Pin Definitions
LORA_SPIBUS = 1 # SPI bus number
LORA_MOSI = 11 # GPIO11 on Raspberry Pi Pico
LORA_MISO = 12 # GPIO12 on Raspberry Pi Pico
LORA_CLK = 10 # GPIO10 on Raspberry Pi Pico
LORA_CS = 3 # GPIO3 on Raspberry Pi Pico
LORA_RST = 15 # GPIO15 on Raspberry Pi Pico
LORA_GPIO = 2 # GPIO2 on Raspberry Pi Pico 
LORA_IRQ = 20 # GPIO20 on Raspberry Pi Pico

# LoRa Configuration Constants
# These constants are used to configure the LoRa module and should match the values used in the sender configuration.
LORA_FREQUENCY=868 # Frequency in MHz
LORA_BANDWIDTH=500.0 # Bandwidth in kHz
LORA_SPREADINGFACTOR=12 # Spreading factor (7-12)
LORA_CODINGRATE=8 # Coding rate (5-8)
LORA_SYNCWORD=0x18 # Sync word for private networks
LORA_POWER=10 # Transmit power in dBm
LORA_CURRENTLIMIT=60.0 # Current limit in mA
LORA_PREAMBLELENGTH=8 # Preamble length in symbols

# Wi-Fi Credentials
# Replace with your Wi-Fi credentials
WIFI_SSID = "myssid"  # Wi-Fi SSID
WIFI_PASSWORD = "mypassword"  # Wi-Fi password

# NTP Server Settings
NTP_SERVER = "0.uk.pool.ntp.org"  # NTP server address

# MQTT Broker Settings
MQTT_BROKER = "192.168.0.5"  # Replace with your broker's address
MQTT_PORT = 1883 # MQTT port
MQTT_DATA_TOPIC = "allotment/data" # Topic for data packets
MQTT_MESSAGE_TOPIC = "allotment/message" # Topic for message packets
MQTT_USERNAME = "mqttuser"  # Set your MQTT username
MQTT_PASSWORD = "mqttpassword"  # Set your MQTT password
CLIENT_ID: bytes = ubinascii.hexlify(network.WLAN(network.AP_IF).config("mac")[-3:])  # Unique ID for the client
